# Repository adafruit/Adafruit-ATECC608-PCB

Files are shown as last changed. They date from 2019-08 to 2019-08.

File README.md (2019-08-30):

## Adafruit Adafruit ATECC608 Breakout Board - STEMMA QT / Qwiic PCB

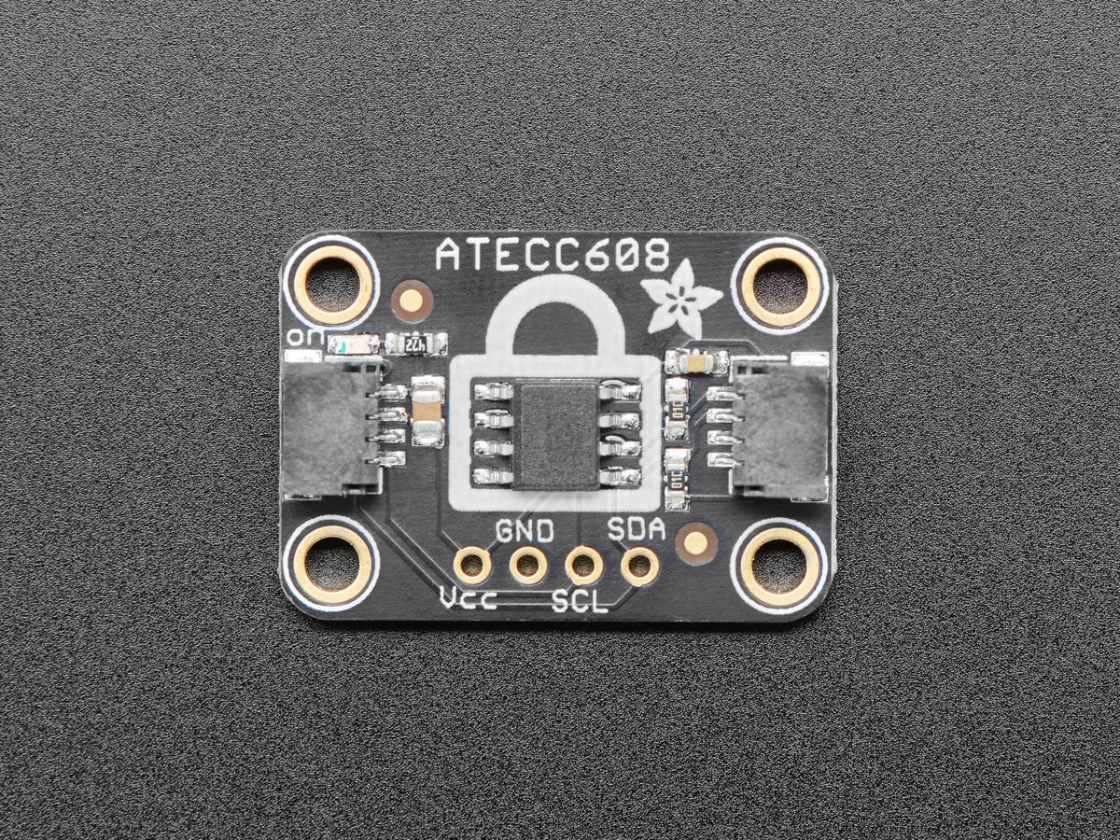
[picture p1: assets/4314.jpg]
<a href="http://www.adafruit.com/products/4314"><br/>
Click here to purchase one from the Adafruit shop</a>

PCB files for the Adafruit Adafruit ATECC608 Breakout Board - STEMMA QT / Qwiic. 

Format is EagleCAD schematic and board layout
* https://www.adafruit.com/product/4314

### Description

You've got secrets, and you want to keep them safe? Most microcontrollers are not designed to protect against snoopers, but a crypto-authentication chip can be used to lock away private keys securely. Once the private key is saved inside, it can't be read out, all you can do is send it challenge-response queries. That means that even if someone gets hold of your hardware and can read back the firmware, they wont be able to extract the secret!

The ATECC608 is the latest crypto-auth chip from Microchip, and it uses I2C to send/receive commands. Once you 'lock' the chip with your details, you can use it for ECDH and AES-128 encrypt/decrypt/signing. There's also hardware support for random number generation, and SHA-256/HMAC hash functions to  greatly speed up a slower micro's cryptography commands.

### License

Adafruit invests time and resources providing this open source design, please support Adafruit and open-source hardware by purchasing products from [Adafruit](https://www.adafruit.com)!

Designed by Limor Fried/Ladyada for Adafruit Industries.

Creative Commons Attribution/Share-Alike, all text above must be included in any redistribution. 
See license.txt for additional details.

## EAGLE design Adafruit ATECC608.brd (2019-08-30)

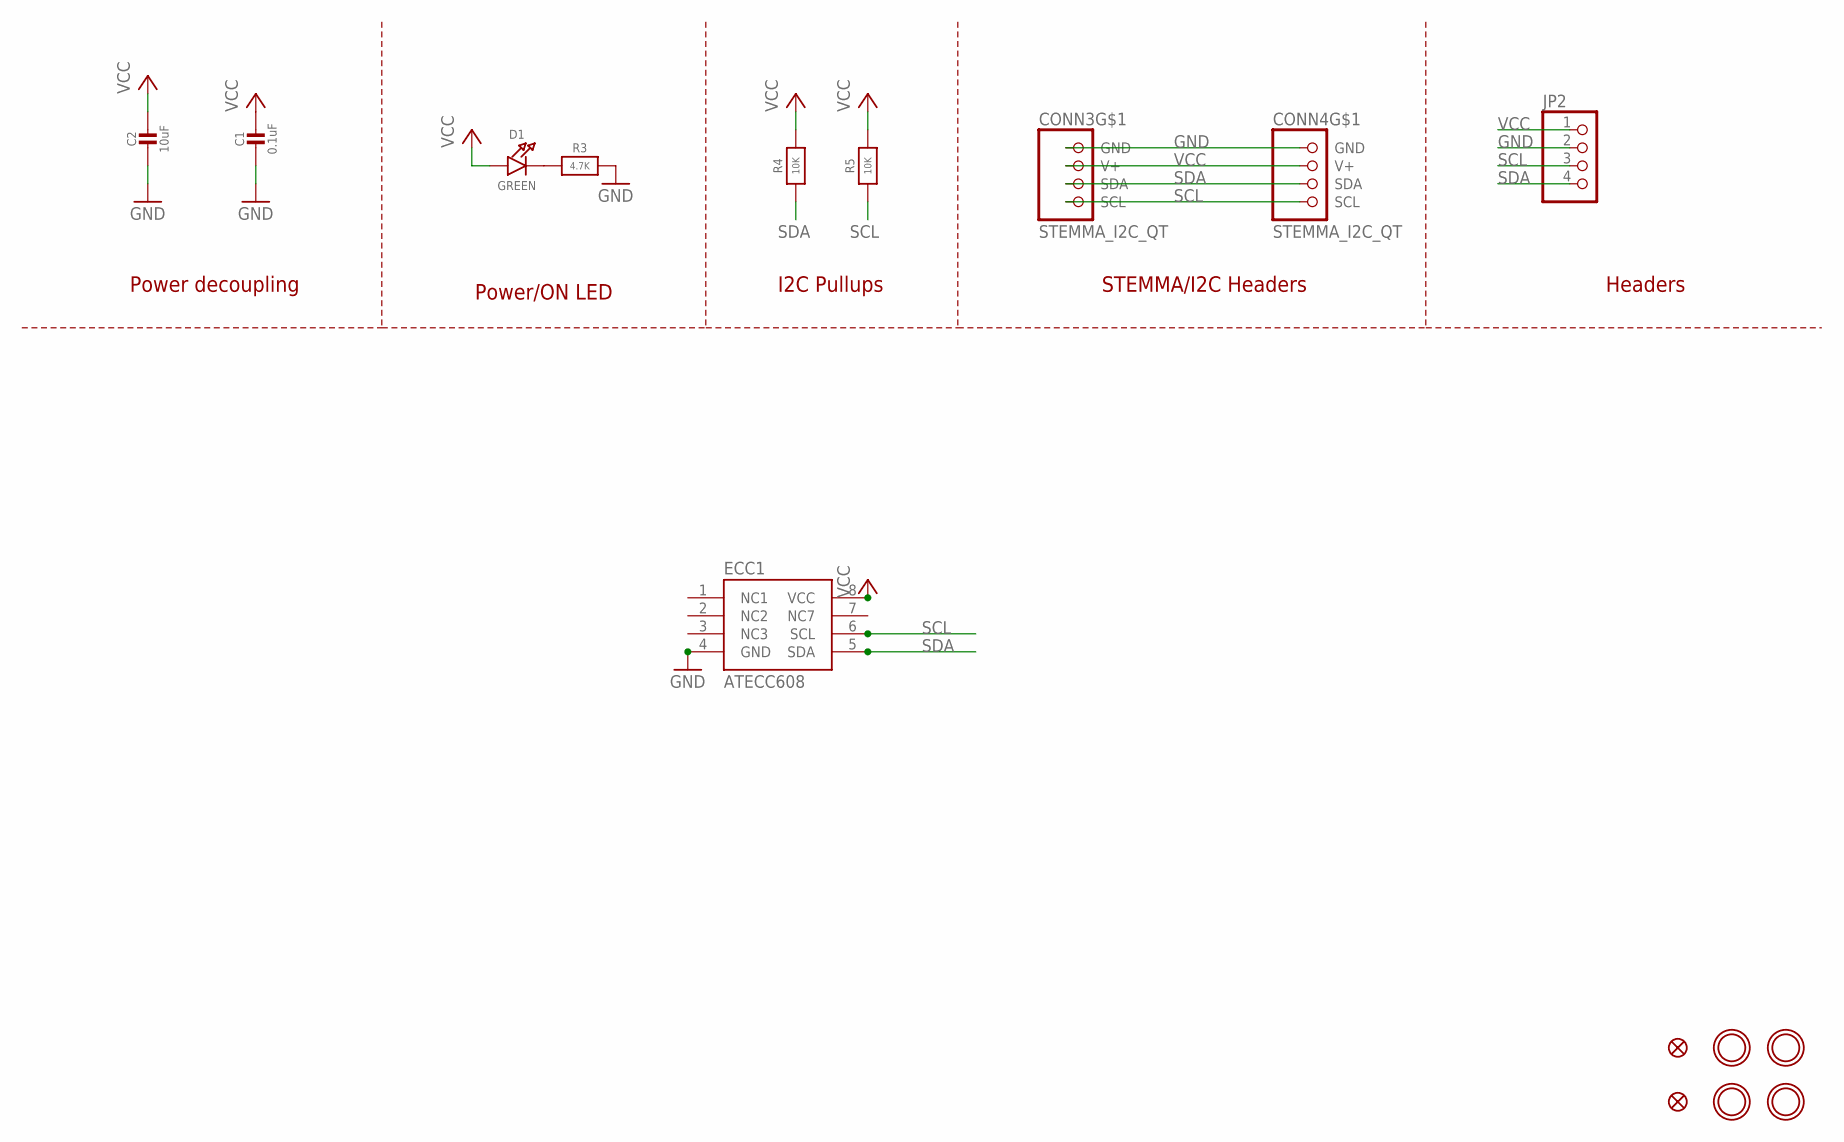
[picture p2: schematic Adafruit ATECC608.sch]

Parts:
C1: 0.1uF; 0603-NO
C2: 10uF; 0805-NO
CONN3, CONN4: STEMMA_I2C_QT; JST_SH4
D1: GREEN; CHIPLED_0603_NOOUTLINE
ECC1: ATECC608; SOIC8
FID3, FID4: FIDUCIAL_1MM
JP2: HEADER-1X4ROUND; 1X04_ROUND
R3: 4.7K; 0603-NO
R4, R5: 10K; 0603-NO
U$11, U$12, U$14, U$15: MOUNTINGHOLE2.5; MOUNTINGHOLE_2.5_PLATED

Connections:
GND: C1.2, C2.2, CONN3.1 (GND), CONN4.1 (GND), ECC1.4 (GND), JP2.2, R3.2
unnamed: D1.C, R3.1
SCL: CONN3.4 (SCL), CONN4.4 (SCL), ECC1.6 (SCL), JP2.3, R5.1
SDA: CONN3.3 (SDA), CONN4.3 (SDA), ECC1.5 (SDA), JP2.4, R4.1
VCC: C1.1, C2.1, CONN3.2 (V+), CONN4.2 (V+), D1.A, ECC1.8 (VCC), JP2.1, R4.2, R5.2

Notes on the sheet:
Power/ON LED
Power decoupling
I2C Pullups
STEMMA/I2C Headers
Headers

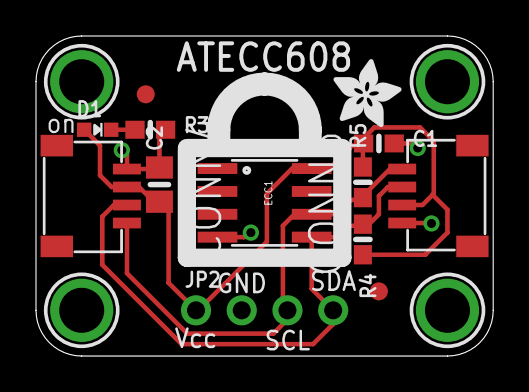
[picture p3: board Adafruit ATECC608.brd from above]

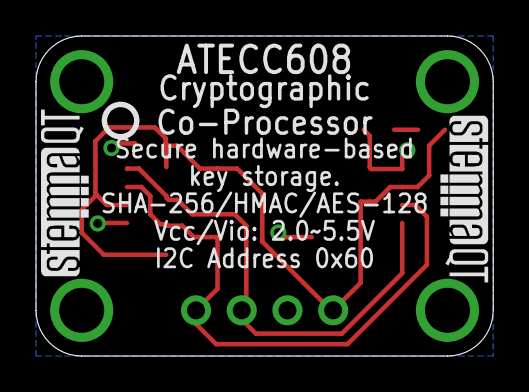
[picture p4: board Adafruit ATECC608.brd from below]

Board: 2 copper layers, 25.4 x 17.8 mm, 20 parts (3 on the bottom side), 5 nets.

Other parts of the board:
U$17: ADAFRUIT_3.5MM
U$18: PCBFEAT-REV-040
U$19, U$20: STEMMAQT

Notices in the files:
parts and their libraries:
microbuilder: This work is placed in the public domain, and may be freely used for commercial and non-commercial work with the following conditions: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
